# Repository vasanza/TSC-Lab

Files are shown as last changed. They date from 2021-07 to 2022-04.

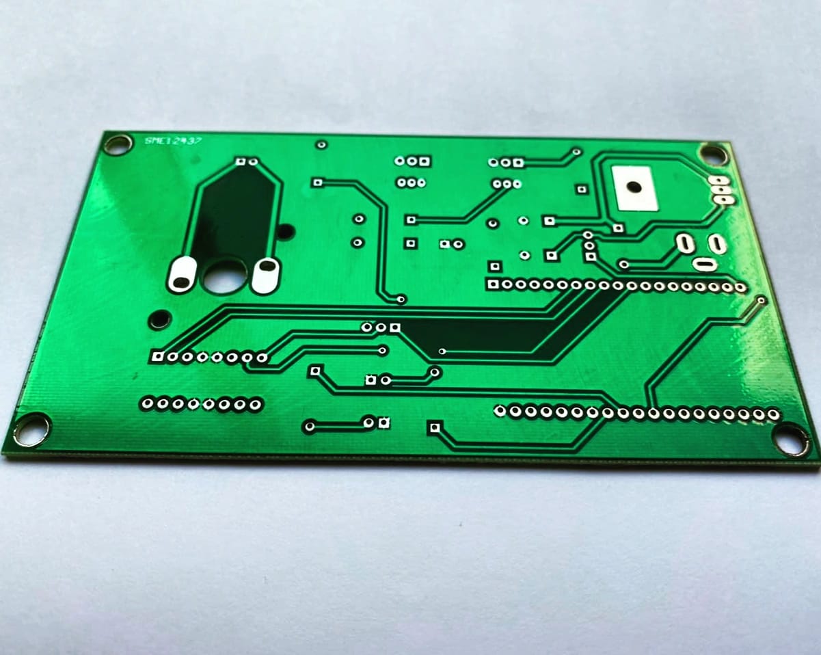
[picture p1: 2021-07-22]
TSC-Lab/PCB2.jpeg

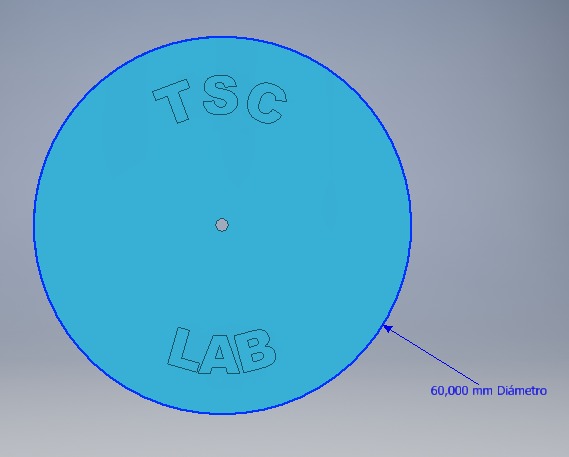
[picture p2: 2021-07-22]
3DPrint/disco.jpeg

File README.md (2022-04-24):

# ⭐⭐⭐⭐⭐ TEMPERATURE AND SPEED CONTROL LAB (TSC-LAB)
- ➡️ #TSCLab #TSC_Lab #TSCLAB #TSC
# Open Source Licenses
oshw_facts

# Open hardware Certification
- https://certification.oshwa.org/ec000003.html
OSHWA TSC-LAB

# About TSC-Lab
TSC-Lab 2
- The Temperature and Speed Control Lab (TSC-Lab) is an application of feedback control with an ESP32, an LED, two heaters, two temperature sensors, one direct current motor and an optical encoder as a revolution per minute (rpm) meter. The heater power output is adjusted to maintain the desired temperature setpoint. Thermal energy from the heater is transferred by conduction, convection, and radiation to the temperature sensor. Heat is also transferred away from the device to the surroundings. On the other hand, the motor speed is adjusted using a motor driver and with PWM signals, allowing the reference speed to be reached using the rpm meter.

# PCB (Top Layer)
PCB1

# PCB (Bottom Layer)
PCB2

# 3D printed parts
TSC-Lab1

# Web page
- http://www.tsc-lab.com/

# Blog
- https://tsc-lab.blogspot.com/

# DataSet
- http://ieee-dataport.org/4138
- http://ieee-dataport.org/4477

# Repository technical specifications
- **IDE:** Arduino 1..8.13
- **DEVICE:** TSC-LAB
- **Hardware Core:** ESP32 - WROOM32

# Keynote
## Clone
- git status
- git clone https://github.com/vasanza/TSC-Lab.git

## Switched to Branch
- git branch -a
- git checkout NameBranch

## New Branch
- git checkout -b NameBranch

## Push
- git pull origin NameBranch
- git status
- git add .
- git status
- git commit -m "message"
- git push origin NameBrach

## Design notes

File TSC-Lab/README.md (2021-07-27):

# Design of printed circuit boards PCBs in Altium Designer 
- https://tsc-lab.blogspot.com/

# PCB (Top Layer)
TSC-Lab 4
PCB1

# PCB (Bottom Layer)
TSC-Lab 5
PCB2

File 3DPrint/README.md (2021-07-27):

# 3D printed parts 
- https://tsc-lab.blogspot.com/

TSC-Lab1
TSC-Lab2

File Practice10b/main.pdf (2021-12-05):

## TEMPERATURE AND SPEED CONTROL LAB (TSC-LAB)

Practice 10: Data acquisition with square velocity input https://tsc-lab.blogspot.com/2021/06/practice-10-data-acquisition-with.html

- Blog: https://tsc-lab.blogspot.com/
- GitHub: https://github.com/vasanza/TSC-Lab
- Matlab functions: https://github.com/vasanza/Matlab_Code
- IEEEDataPort: http://ieee-dataport.org/4138
- TSC-LAB configurations
- int dutyCycleInitial = 255;
- int dutyCycleFinish = 0;
- int period = 13000;
- int cycles = 50;
- 1 sample per second

## Raw dataset preparation

clear;clc;%clear all
addpath(genpath('./src'))%functions folders datapath = fullfile('./data/');%data folder

## Raw dataset preprocessing

filenames = FindCSV(datapath);%List All CSV files data=readtable(fullfile(datapath,filenames(1).name));%Select i CSV file data=table2array(data);
DataNorm = fNormalization(data(:,1));%Normalization
DataFeatures = [max(DataNorm) min(DataNorm) mean(DataNorm)... median(DataNorm) rms(DataNorm) std(DataNorm) ];%Feature extraction

## Plot Raw TSC-LAB dataset

figure
plot(data);xlabel('Samples');ylabel('RPM'); title('Motor Speed');
legend('RPM','PWM');

## Plot Normalization dataset

figure
plot(DataNorm);xlabel('Samples');ylabel('Normalized Values'); title('Normalized data graph');
legend('RPM');

## Select a case

IN=data(:,end);%RPM motor
OUT=data(:,1);%PWM
figure
plot(OUT)
title('OUT');

## System Identification

ident

Warning: The "ident" command is obsolete and may be removed in a future release of MATLAB. Use the "systemIdentification" command instead.

Created preference file C:\Users\vasan\Documents\MATLAB\idprefs.mat.
Type HELP MIDPREFS if you want to move this file.

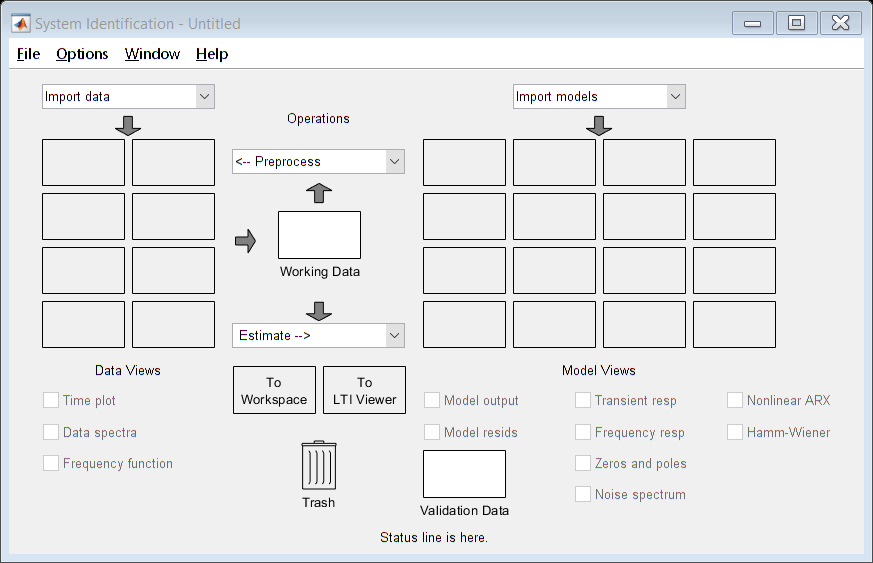
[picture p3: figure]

## Open the Classification Learner

%regressionLearner
%classificationLearner

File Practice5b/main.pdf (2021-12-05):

## TEMPERATURE AND SPEED CONTROL LAB (TSC-LAB)

Práctica 5: Activation of Transistor 1 and 2, also Reading of temperature sensor 1 and 2 https://tsc-lab.blogspot.com/2021/05/practica-5-activation-of-transistor-1.html

- Blog: https://tsc-lab.blogspot.com/
- GitHub: https://github.com/vasanza/TSC-Lab
- Matlab functions: https://github.com/vasanza/Matlab_Code
- IEEEDataPort: http://ieee-dataport.org/4138
- TSC-LAB configurations
- int period = 15; //medium period in minutes
- int freq_sampling = 100; // sampling time
- int ciclos = 20; // sampling time
- 1 sample per second

## Raw dataset preparation

clear;clc;%clear all
addpath(genpath('./src'))%functions folders datapath = fullfile('./data/');%data folder

## Raw dataset preprocessing

filenames = FindCSV(datapath);%List All CSV files data=readtable(fullfile(datapath,filenames(1).name));%Select i CSV file data=table2array(data);
DataNorm = fNormalization(data(:,1:2));%Normalization
DataFeatures = [max(DataNorm) min(DataNorm) mean(DataNorm)... median(DataNorm) rms(DataNorm) std(DataNorm) ];%Feature extraction

## Plot Raw TSC-LAB dataset

figure
plot(data);xlabel('Samples');ylabel('°C'); title('Temperature');
legend('Temp1','Temp2','PWM1','PWM2');

## Plot Normalization dataset

figure
plot(DataNorm);xlabel('Samples');ylabel('Normalized Values'); title('Normalized data graph');
legend('Temp1','Temp2');

## Select a case

num = input('Enter a case: '); switch num
case 1 %Temp1
IN=data(:,end-1);%temp1
OUT=data(:,1);%PWM1
case 2 %Temp2
IN=data(:,end);%temp1
OUT=data(:,2);%PWM1
case 3 %Temp1 and Temp2
IN=[(data(:,end) + data(:,end-1))/2];%temp1 OUT=data(:,1);%PWM1
end
figure
plot(OUT)
title('OUT');

## System Identification

ident

Warning: The "ident" command is obsolete and may be removed in a future release of MATLAB. Use the "systemIdentification" command instead.

Created preference file C:\Users\vasan\Documents\MATLAB\idprefs.mat.
Type HELP MIDPREFS if you want to move this file.


## Open the Classification Learner

%regressionLearner
%classificationLearner

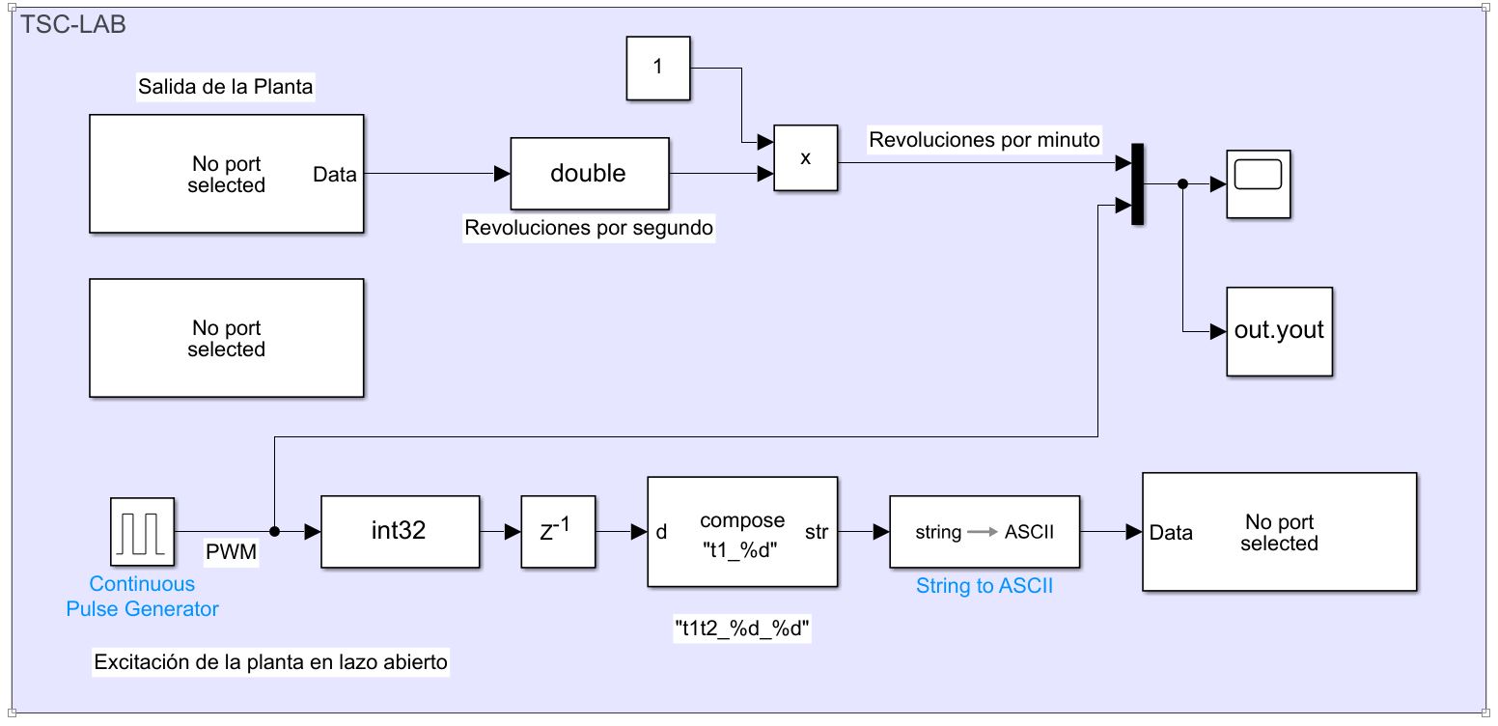
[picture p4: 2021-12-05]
Practice11/Practice11_Str/Practice11_Str.JPG

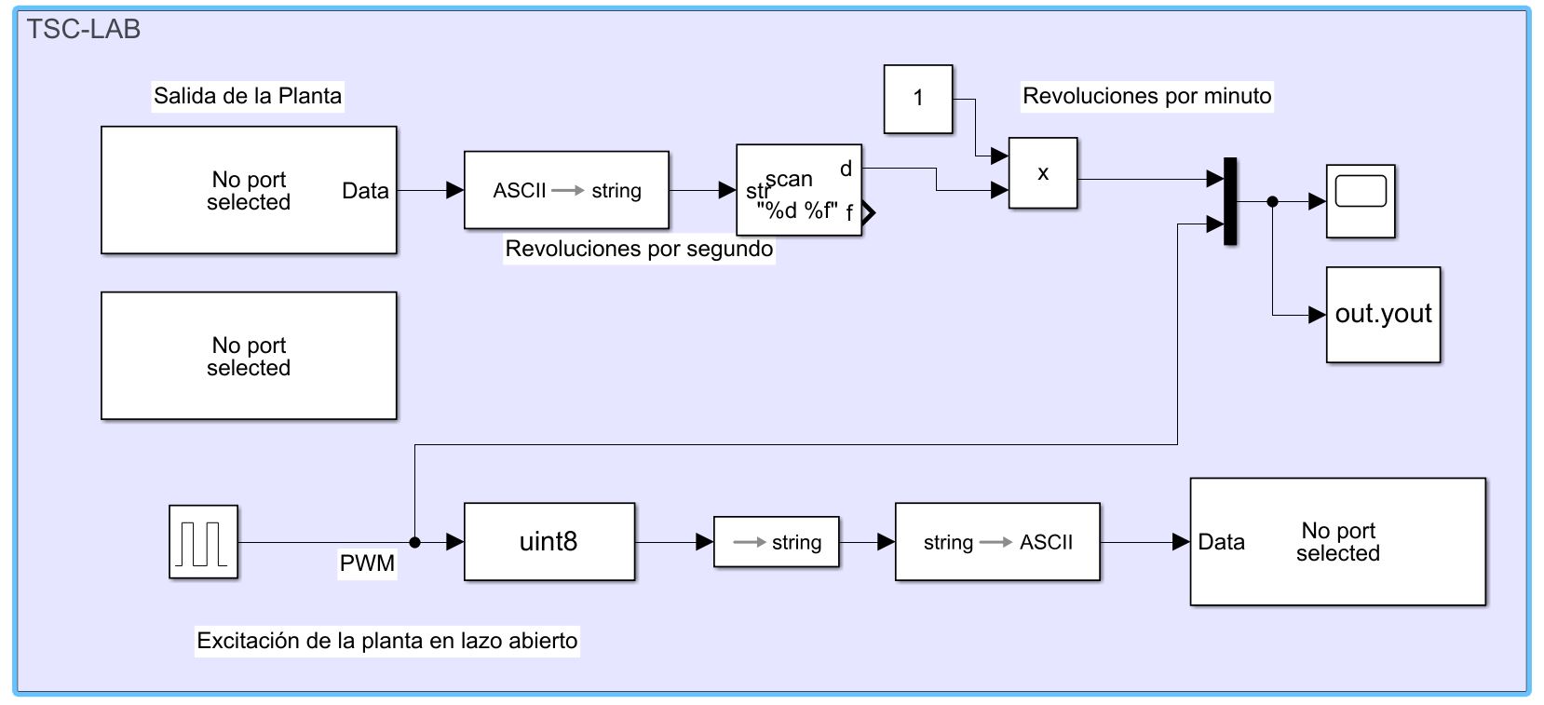
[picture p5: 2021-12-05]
Practice12/Practice12_String/practice12_String.JPG

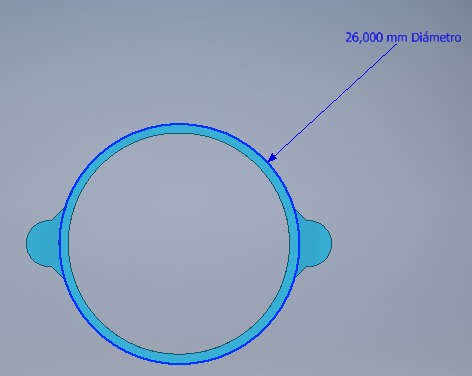
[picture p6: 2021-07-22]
3DPrint/case_motor.jpeg

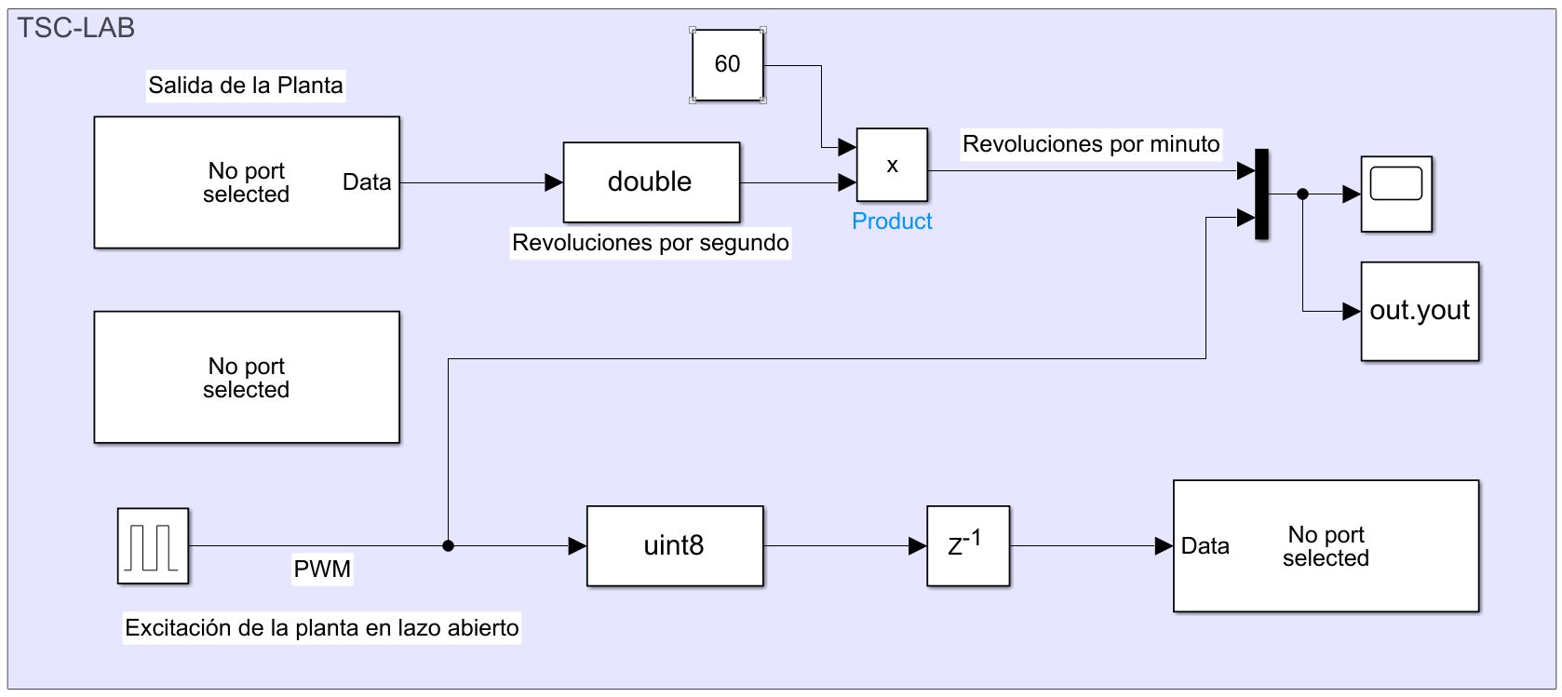
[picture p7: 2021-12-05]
Practice12/Practice12_Byte/Practice12_Byte.JPG

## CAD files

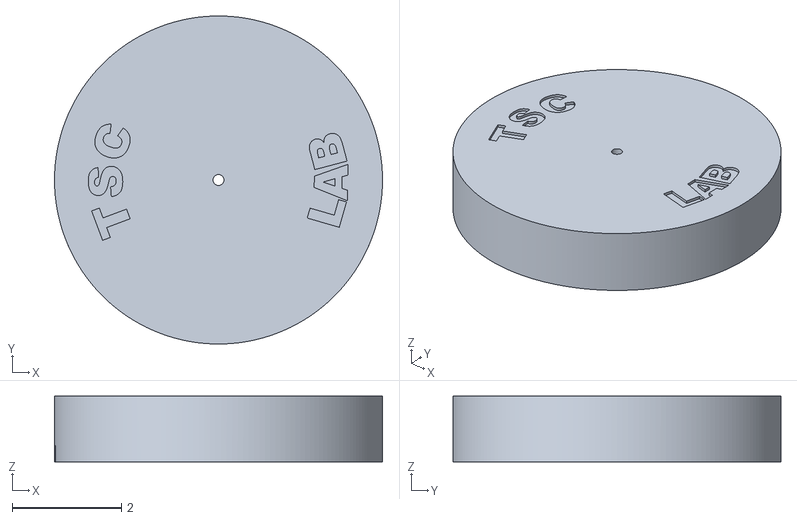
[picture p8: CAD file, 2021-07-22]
3DPrint/disco_lf.stl
6.00 x 6.00 x 1.20

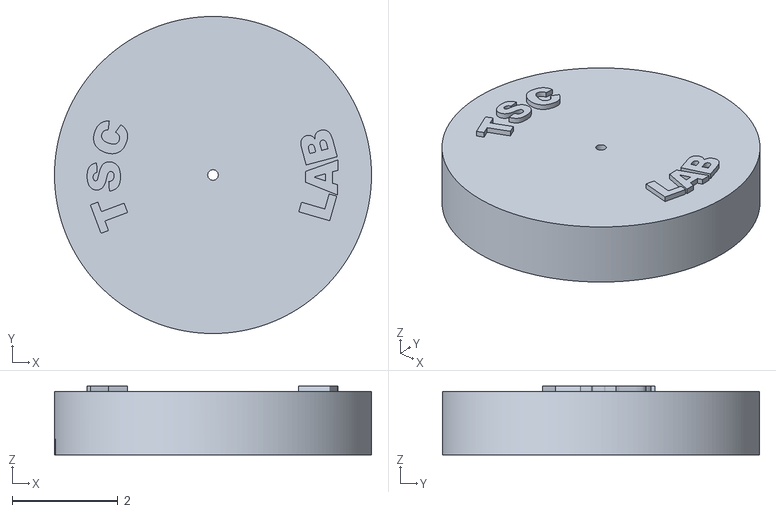
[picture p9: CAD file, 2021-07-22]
3DPrint/disco.stl
6.00 x 6.00 x 1.30

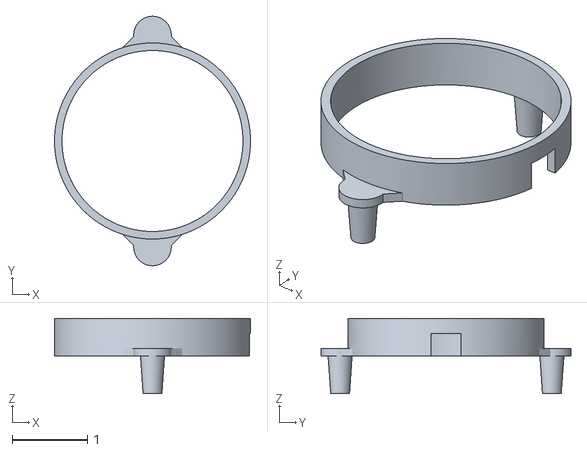
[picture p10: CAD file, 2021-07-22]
3DPrint/case_motor.stl
2.60 x 3.31 x 1.00

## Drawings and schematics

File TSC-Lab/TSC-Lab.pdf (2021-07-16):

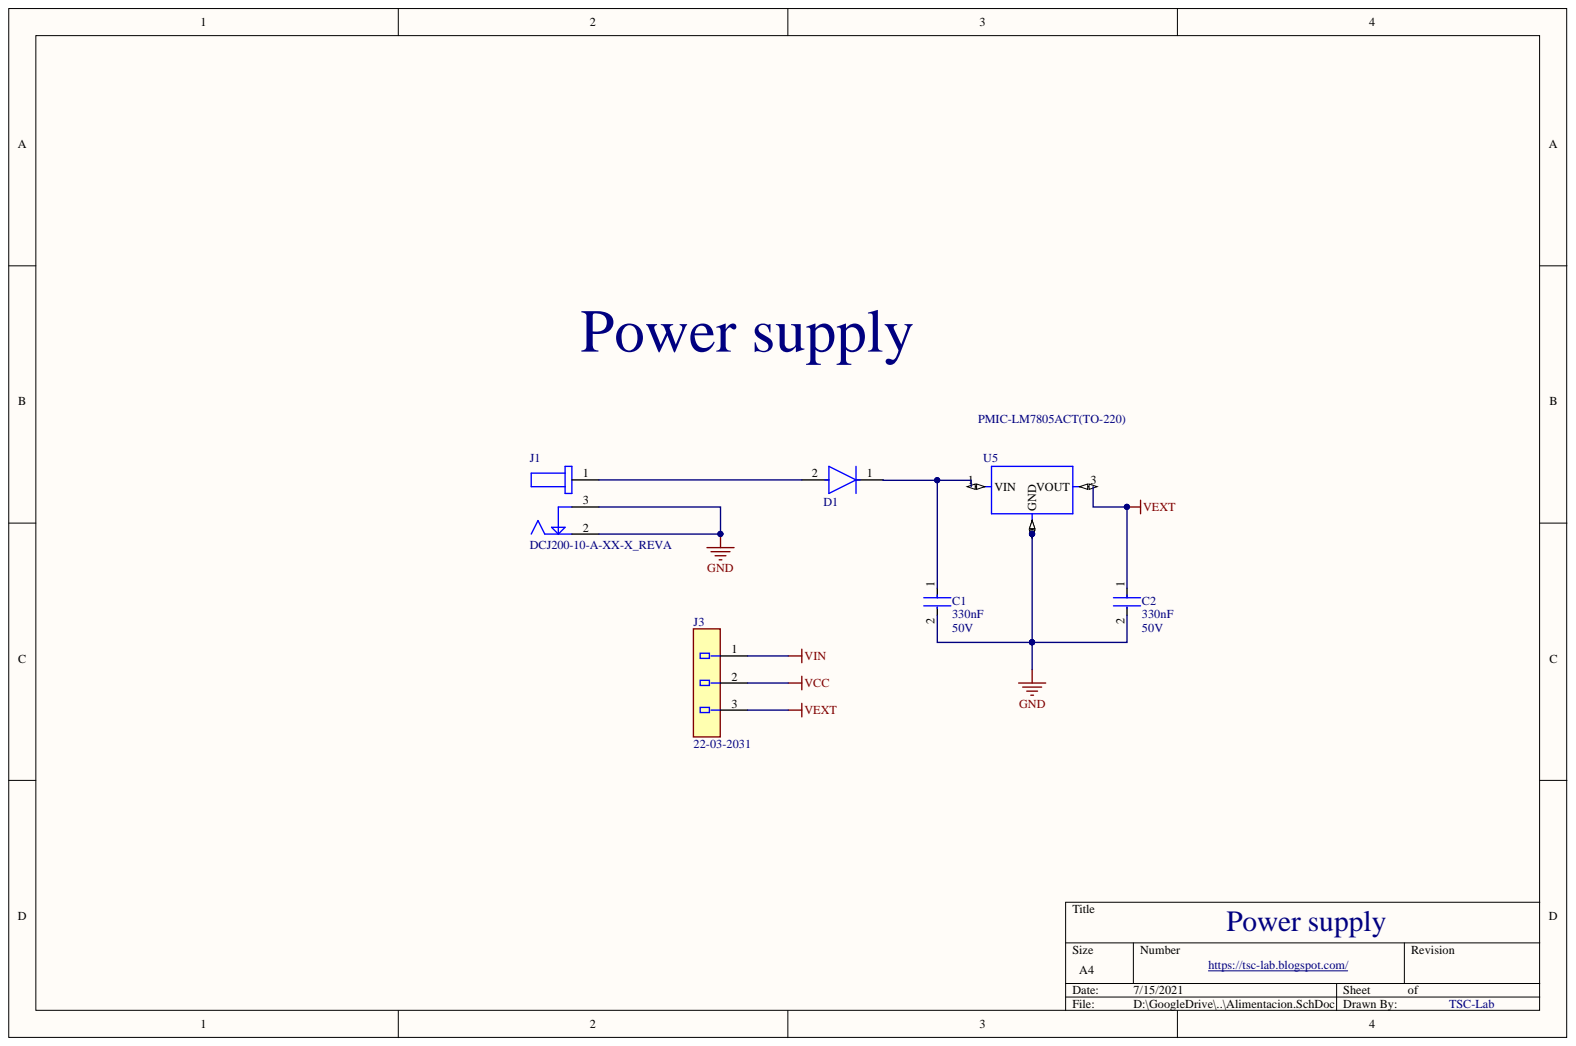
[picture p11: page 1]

Size A4 | Number https://tsc-lab.blogspot.com/ | Revision

Date: 7/15/2021 | Sheet of
File: D:\GoogleDrive\..\Alimentacion.SchDoc | Drawn By: TSC-Lab

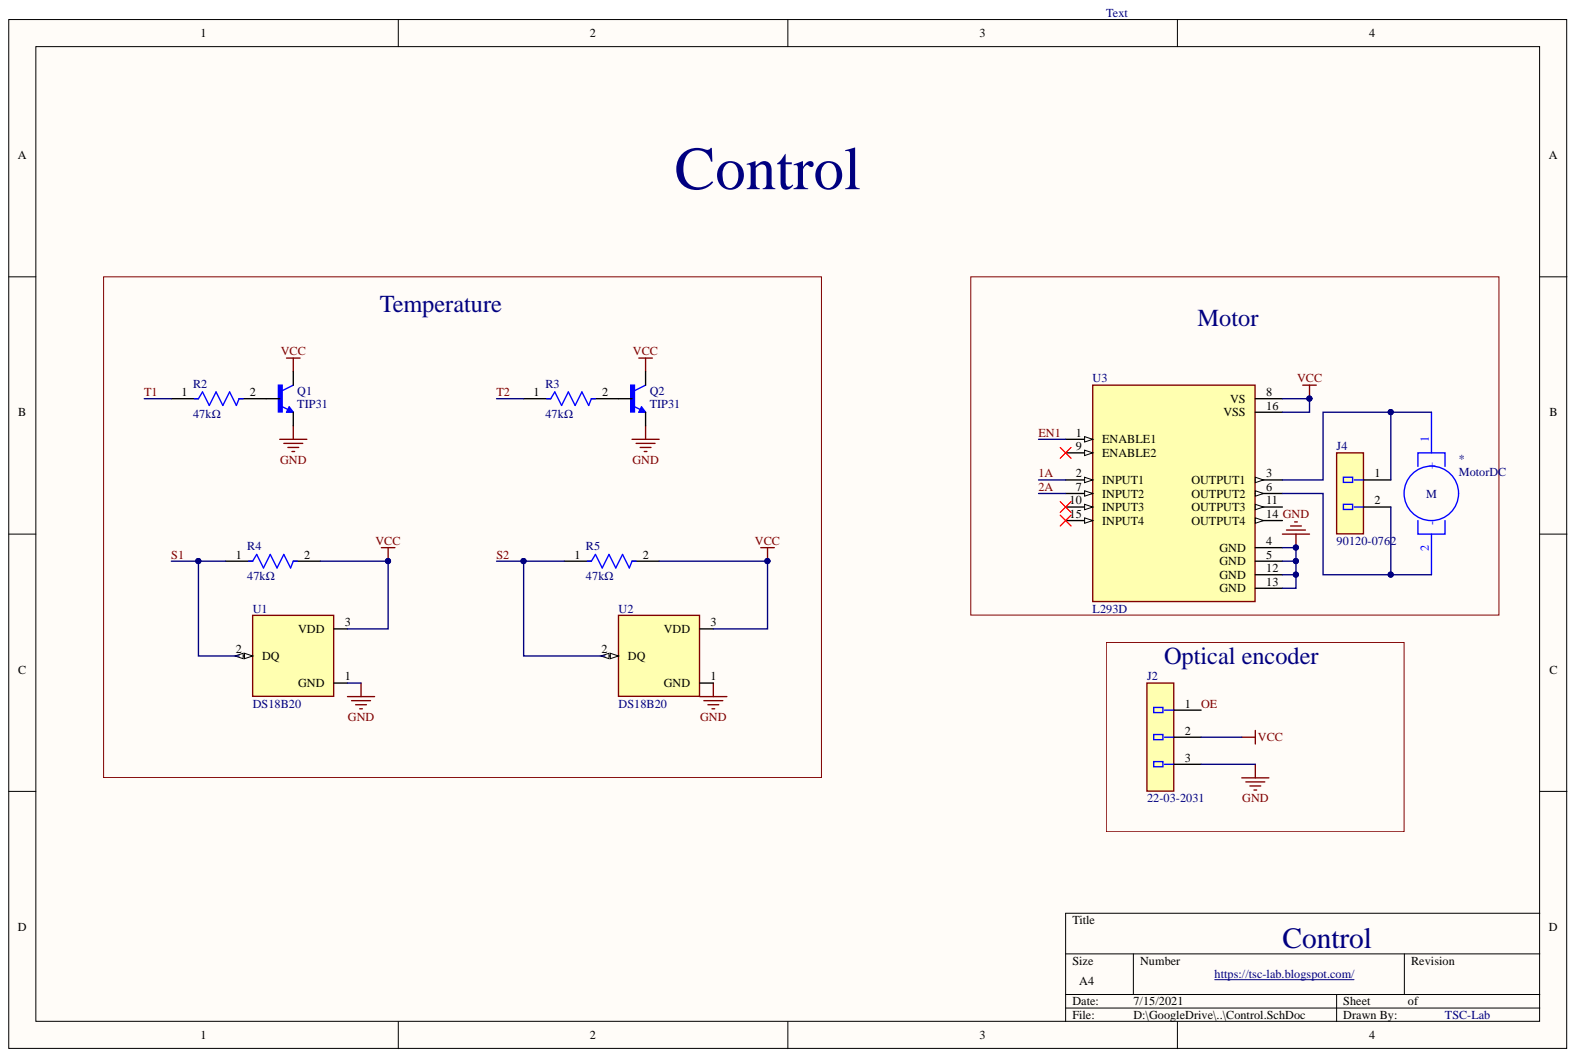
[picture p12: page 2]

1 1 | GND

Size A4 | Number https://tsc-lab.blogspot.com/ | Revision

Date: 7/15/2021 | Sheet of
File: D:\GoogleDrive\..\Control.SchDoc | Drawn By: TSC-Lab

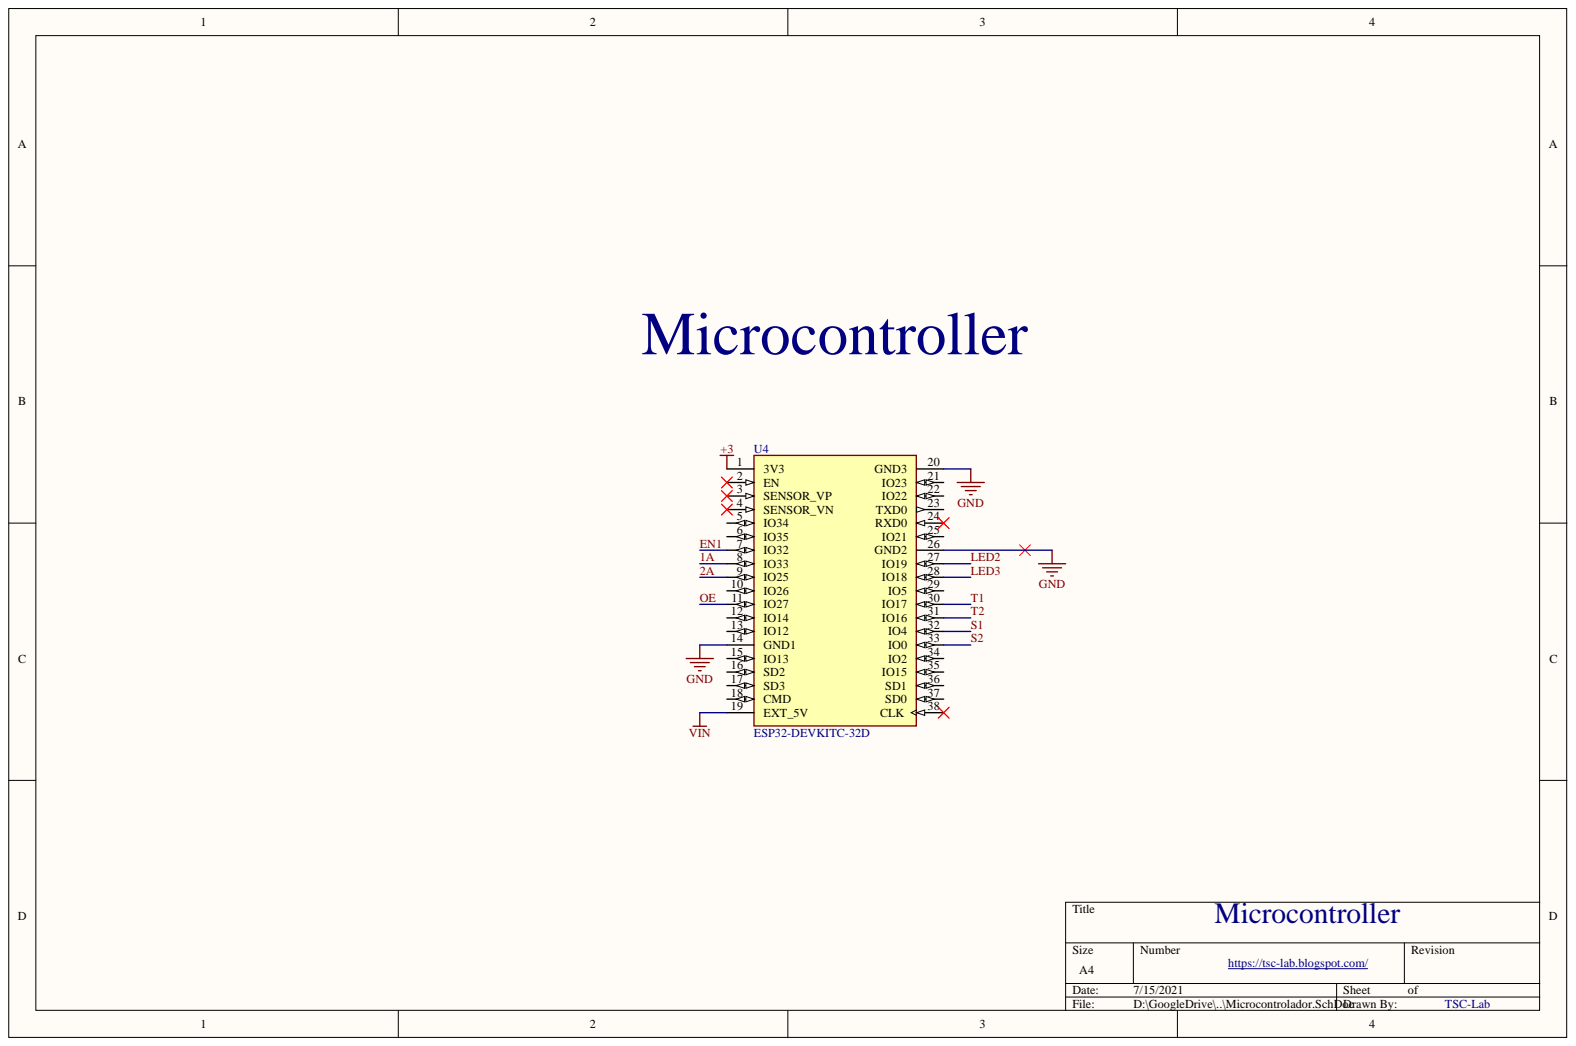
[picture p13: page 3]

Size A4 | Number https://tsc-lab.blogspot.com/ | Revision

Date: 7/15/2021 | Sheet of
File: D:\GoogleDrive\..\Microcontrolador.SchDocDrawn By: | TSC-Lab

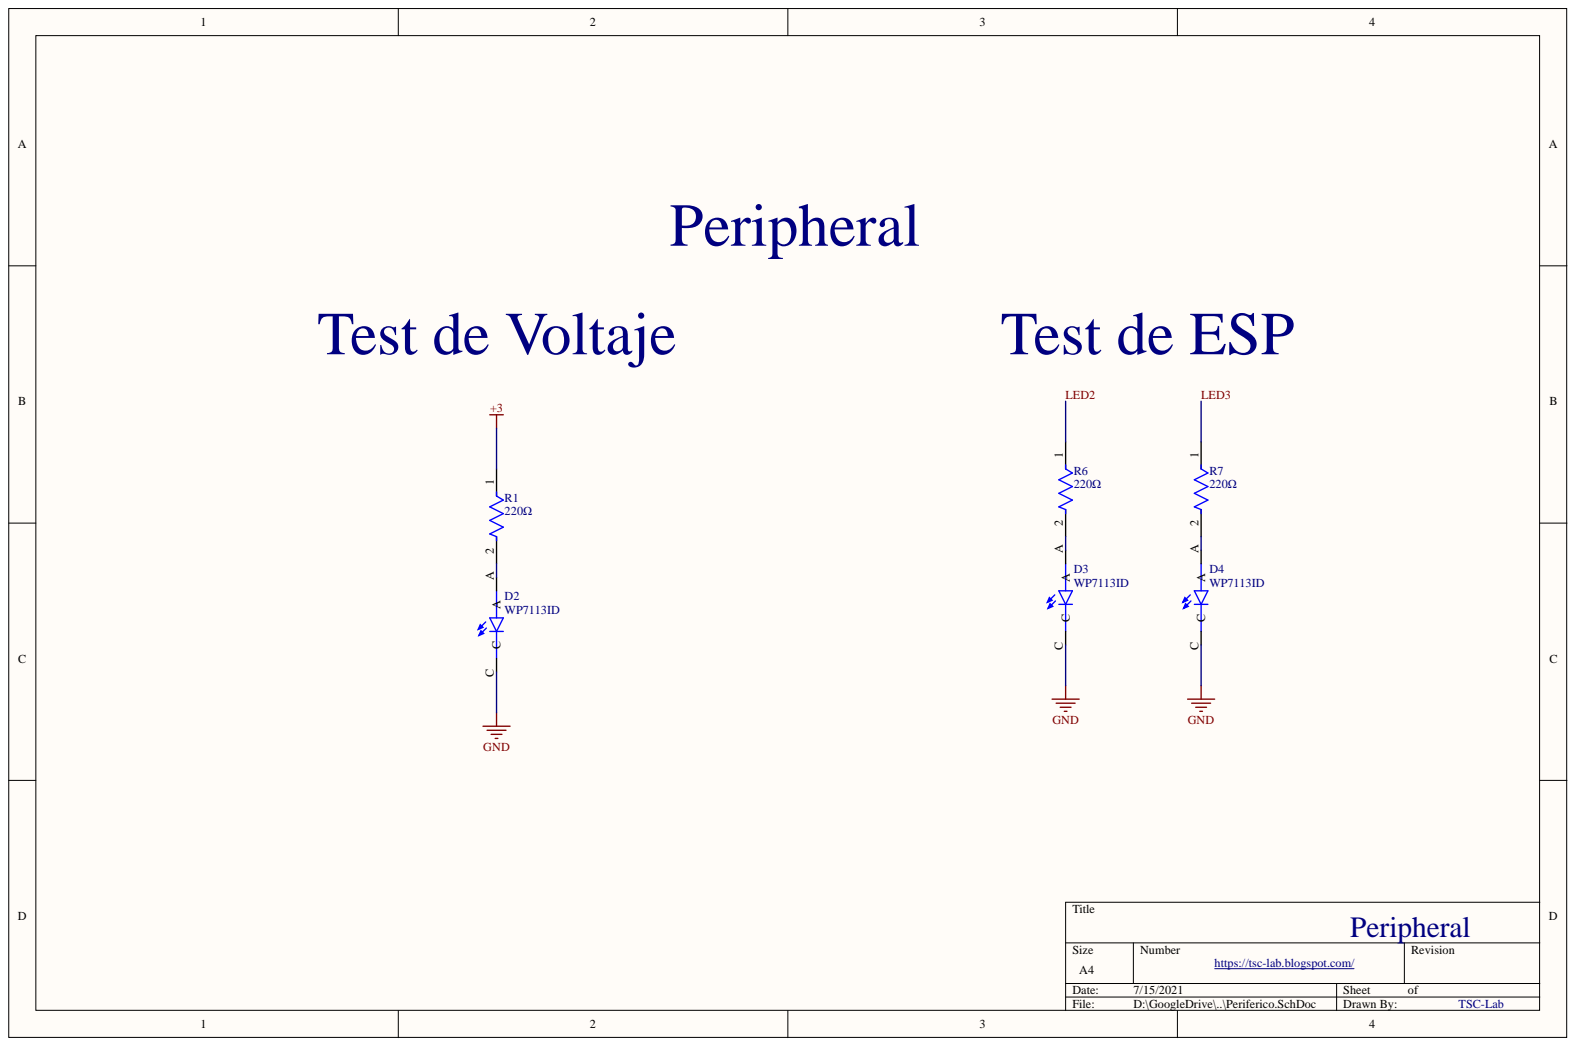
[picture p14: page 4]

Size A4 | Number https://tsc-lab.blogspot.com/ | Revision

Date: 7/15/2021 | Sheet of
File: D:\GoogleDrive\..\Periferico.SchDoc | Drawn By: TSC-Lab

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
D | D
C | C
B | B
A | A

Title

Size A4 | Number https://tsc-lab.blogspot.com/ | Revision
Date: 7/15/2021 | Sheet of
File: D:\GoogleDrive\..\TSC-Lab.SchDoc | Drawn By: TSC-Lab

Designator
Alimentacion.SchDoc

Designator
Microcontrolador.SchDoc

Designator
Control.SchDoc

Designator
Periferico.SchDoc

# TSC-LAb

# 1. Power supply 2. Microcontroller 3. Control 4. Peripheral

# TSC-Lab

The Temperature and Speed Control Lab (TSC-Lab) is an application of feedback control with an ESP32, an LED, two heaters, two temperature sensors, one direct current motor and an optical encoder as a revolution per minute (rpm) meter. The heater power output is adjusted to maintain the desired temperature setpoint. Thermal energy from the heater is transferred by conduction, convection, and radiation to the temperature sensor. Heat is also transferred away from the device to the surroundings. On the other hand, the motor speed is adjusted using a motor driver and with PWM signals, allowing the reference speed to be reached using the rpm meter.

The practice guides that were used in the data acquisition process are detailed in the following blog:
https://tsc-lab.blogspot.com/p/summary.html

The codes used are in the following repository:
https://github.com/vasanza/TSC-Lab

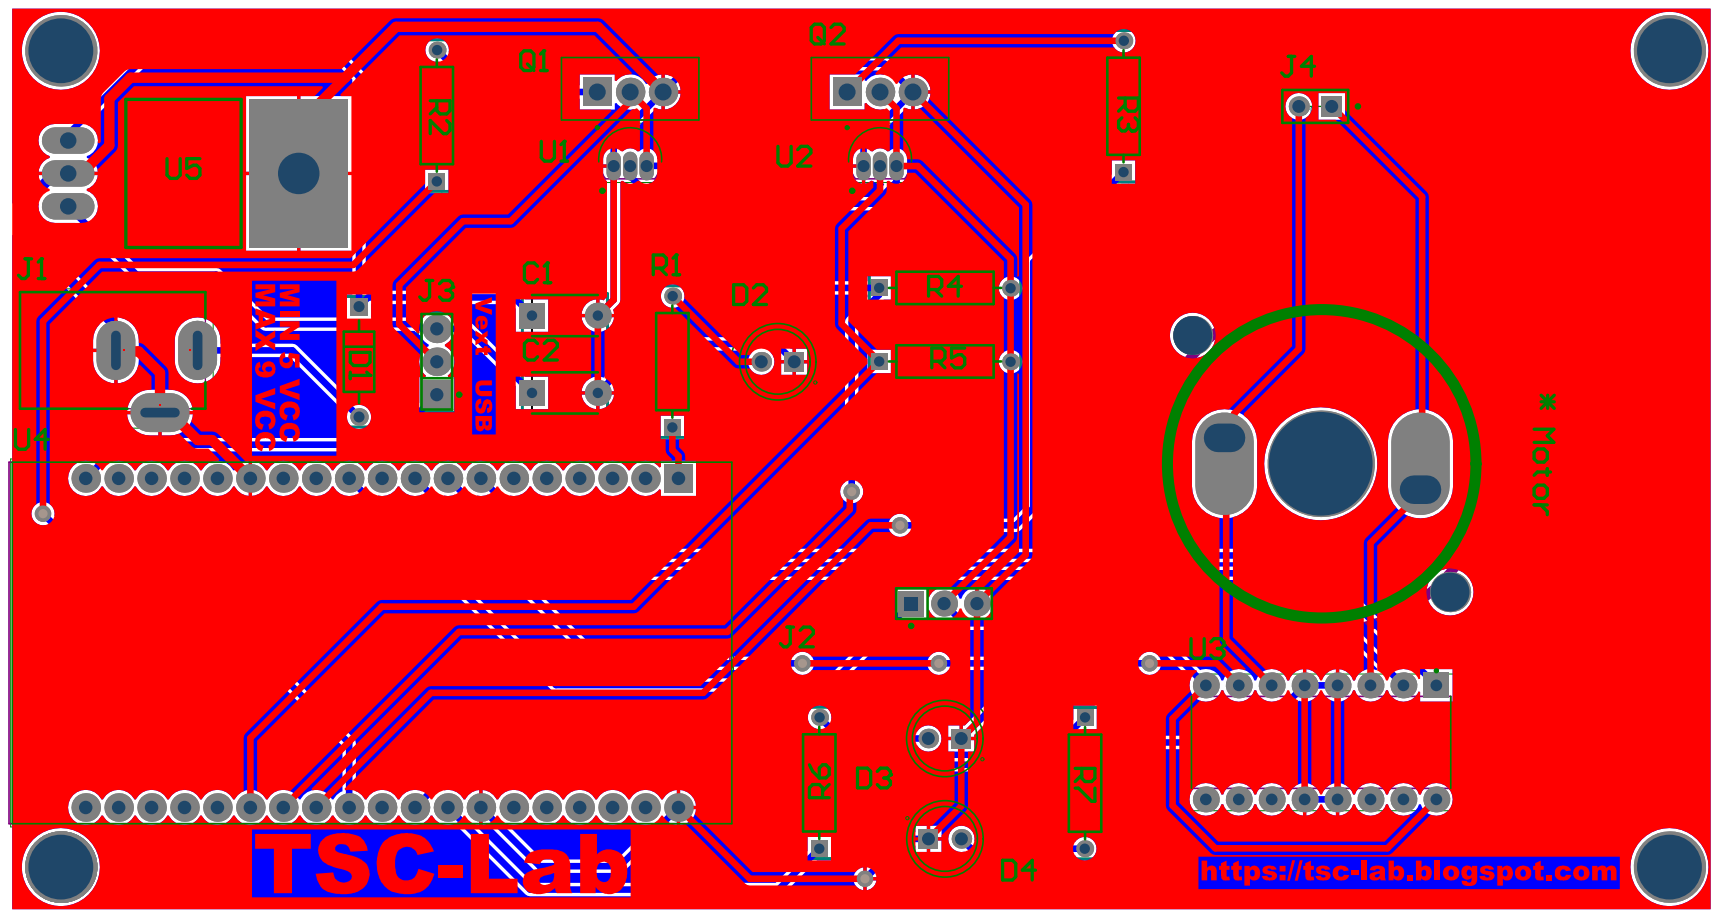
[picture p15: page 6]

Comment | Description | Designator | Footprint | LibRef | Quantity
MotorDC | PCBComponent_1 | MotorDC | 1
Cap_Kemet_C322C334CAPCER0.33UF 50V ZC1 , C2 | Kemet_C322C334M5U5Cap_Kem et_C322C334 | 2
Diode_Vishay_1N4001DIODEGEN PURP 50V D1 | Vishay_1N4001E-E3-5Diode_Vishay_1N4001 | 1
WP7113ID | LED; Thru-Hole; GreenD 2, D3, D 4 | LED_ WP71 13ID | WP7113 ID | 3
DCJ200-10-A-XX-X_REDC Power Jack, Thru-HJ1 | GC T_DCJ200- 10-A-XX- DCJ200-10-A-XX-X_RE | 1
Conn_Molex_22-03-20CON N HEADER 3POS | J2, J3 | Molex_SD-4030-0001_Conn_Molex_22-03-20 | 2
Conn_Molex_90120-07CON N HEADER 2POS | J4 | Molex_90120-0762_0 | Conn_Molex_90120-07 | 1
TIP31 | Bipolar (BJT) TransistoQ1 , Q2 | TO2 54P1060X4 82 X222TIP31 | 2
Res_Vishay_SFR25000RES220 OHM 0.4W 1%R1, R2, R3, R4, R5, R6Vis hay_SFR250000220Res_Vis hay_SFR25000 | 7
DS18B20 | digital thermometer -5U1, U2 | TO-92-TO92127P495HDS18B2 0 | 2
L293D | 4-Channel Motor Driver U3 | DIP880W50P254L2000L293D | 1
ESP32-DEVKITC-32D | Eval Board For Esp-WroU4 | MODULE_ESP32-DEVKIESP32-DEVKITC-32D | 1
PMIC-LM7805ACT(TO-310030049 | U5 | TO-220 | PMIC-LM7805ACT(TO- | 1

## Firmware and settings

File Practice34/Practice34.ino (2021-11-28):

/*
   ****************************** TSC-Lab *******************************
   ***************************** PRACTICE 34 *****************************
   This practice is about use of two core esp-32
   By: Kevin E. Chica O
   More information: https://tsc-lab.blogspot.com/
*/
//temperature
#include <OneWire.h>
#include <DallasTemperature.h>
// GPIO pin 0 is set as OneWire bus
OneWire ourWire1(0);
//GPIO pin 4 is set as OneWire bus
OneWire ourWire2(4);

//A variable or object is declared for our sensor 1
DallasTemperature sensors1(&ourWire1);
//A variable or object is declared for our sensor 2
DallasTemperature sensors2(&ourWire2);

//set parameters
int period_temp = 12; //medium period
int freq_temp = 2000; // sampling time



//motor

//initial setting for data acquisition
int dutyCycleInitial = 255;
int dutyCycleFinish = 0;
int period = 13000;
int cycles = 10;




//separador library
#include <Separador.h>
Separador s;




//motor
int motor1Pin1 = 33;
int motor1Pin2 = 25;
int enable1Pin = 32;

int motor_status = 255;


// Setting PWM properties
const int freq = 30000;
const int pwmChannel = 0;
const int resolution = 8;

//move
String move_motor = "counterclockwise";

int encoder = 27;

void motor( void *pvParameters );

void RPM( void *pvParameters );
void readTemperature( void *pvParameters );

volatile int counter = 0;


void interruption()    // Function that runs during each interrupt
{
  counter++;
}

void setup() {
  Serial.begin(115200);
  //begin temperature sensor
  sensors1.begin();   //Sensor 1 starts
  sensors2.begin();   //Sensor 2 starts


  // sets the pins as outputs:
  pinMode(motor1Pin1, OUTPUT);
  pinMode(motor1Pin2, OUTPUT);
  pinMode(enable1Pin, OUTPUT);

  // configure LED PWM functionalitites
  ledcSetup(pwmChannel, freq, resolution);

  // attach the channel to the GPIO to be controlled
  ledcAttachPin(enable1Pin, pwmChannel);



  attachInterrupt(encoder, interruption, RISING);


  xTaskCreatePinnedToCore(
    motor
    ,  "MotorDC"         // Descriptive name of the function (MAX 8 characters)
    ,  2048              // Size required in STACK memory
    ,  NULL              // INITIAL parameter to receive (void *)
    ,  1                 // Priority, priority = 3 (configMAX_PRIORITIES - 1) is the highest, priority = 0 is the lowest.
    ,  NULL              // Variable that points to the task (optional)
    , 1);                // core 1


  xTaskCreatePinnedToCore(
    RPM
    ,  "RPM"              // Descriptive name of the function (MAX 8 characters)
    ,  2048              // Size required in STACK memory
    ,  NULL              // INITIAL parameter to receive (void *)
    ,  1                 // Priority, priority = 3 (configMAX_PRIORITIES - 1) is the highest, priority = 0 is the lowest.
    ,  NULL              // Variable that points to the task (optional)
    , 1);                // core 1

    xTaskCreatePinnedToCore(
    readTemperature
    ,  "rTemp"              // Descriptive name of the function (MAX 8 characters)
    ,  2048              // Size required in STACK memory
    ,  NULL              // INITIAL parameter to receive (void *)
    ,  1                 // Priority, priority = 3 (configMAX_PRIORITIES - 1) is the highest, priority = 0 is the lowest.
    ,  NULL              // Variable that points to the task (optional)
    , 0);                // core 0



}

void loop() {
}

void motor( void *pvParameters ) {
  while (1) {
    if (cycles > 0) {
      digitalWrite(motor1Pin1, HIGH);
      digitalWrite(motor1Pin2, LOW);
      ledcWrite(pwmChannel, dutyCycleInitial);

      motor_status = 255;
      vTaskDelay(period);


      digitalWrite(motor1Pin1, HIGH);
      digitalWrite(motor1Pin2, LOW);
      ledcWrite(pwmChannel, dutyCycleFinish);

      motor_status = 0;
      vTaskDelay(period);
      cycles--;
    }
  }
}

void RPM( void *pvParameters ) {
  while (1) {

    vTaskDelay(999);
    Serial.print(counter * 60);
    Serial.print(",");
    Serial.println(motor_status);
    counter = 0;

  }
}



void readTemperature( void *pvParameters ) {
  while (1) {

    uint32_t timer = period_temp * 60000L;

    for ( uint32_t tStart = millis();  (millis() - tStart) < timer;  ) {
      //The command is sent to read the temperature
      sensors1.requestTemperatures();
      //Obtain the temperature in ºC of sensor 1
      float temp1 = sensors1.getTempCByIndex(0);

      //The command is sent to read the temperature
      sensors2.requestTemperatures();
      //Obtain the temperature in ºC of sensor 2
      float temp2 = sensors2.getTempCByIndex(0);

      //print to display the temperature change
      Serial.println();
      Serial.print(temp1);
      Serial.print(",");
      Serial.println(temp2);          
      delay(freq_temp);
    }

  }
}

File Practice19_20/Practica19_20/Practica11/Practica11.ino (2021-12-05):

/*
   ****************************** TSC-Lab *******************************
   ***************************** PRACTICE 11 *****************************
   This practice is about data acquisition with square velocity input
   By: Kevin E. Chica O
   Reviewed: vasanza
   More information: https://tsc-lab.blogspot.com/
*/
//separador library
#include <Separador.h>
Separador s;

//initial setting for data acquisition
#include <OneWire.h>
#include <DallasTemperature.h>

//GPIO pin 4 is set as OneWire bus
OneWire ourWire1(4);
//GPIO pin 0 is set as OneWire bus
OneWire ourWire2(0);

//A variable or object is declared for our sensor 1
DallasTemperature sensors1(&ourWire1);
//A variable or object is declared for our sensor 2
DallasTemperature sensors2(&ourWire2);

//Status of transistors
int t1 = 0;
int t2 = 0;
//pins of transistor
int trans1 = 17;
int trans2 = 16;

//set parameters

int dutyCycle1 = 0;
int dutyCycle2 = 0;
int band = 0;

// Setting PWM properties
const int freq = 30000;
const int pwmChannell = 0;
const int pwmChannel2 = 1;
const int resolution = 8;



void transistor( void *pvParameters );
void temperature( void *pvParameters );
void pwm( void *pvParameters );



void setup() {
  Serial.begin(115200);
  // sets the pins as outputs:
  sensors1.begin();   //Sensor 1 starts
  sensors2.begin();   //Sensor 2 starts

  //transistor 1
  pinMode(trans1, OUTPUT);
  //transitor 2
  pinMode(trans2, OUTPUT);;

  // configure LED PWM functionalitites
  ledcSetup(pwmChannell, freq, resolution);
  ledcSetup(pwmChannel2, freq, resolution);
  // attach the channel to the GPIO to be controlled
  ledcAttachPin(trans1, pwmChannell);
  ledcAttachPin(trans2, pwmChannel2);

  xTaskCreatePinnedToCore(
    transistor
    ,  "trans"         // Descriptive name of the function (MAX 8 characters)
    ,  2048              // Size required in STACK memory
    ,  NULL              // INITIAL parameter to receive (void *)
    ,  1                 // Priority, priority = 3 (configMAX_PRIORITIES - 1) is the highest, priority = 0 is the lowest.
    ,  NULL              // Variable that points to the task (optional)
    , 1);                // core 1

  xTaskCreatePinnedToCore(
    temperature
    ,  "temp"              // Descriptive name of the function (MAX 8 characters)
    ,  2048              // Size required in STACK memory
    ,  NULL              // INITIAL parameter to receive (void *)
    ,  1                 // Priority, priority = 3 (configMAX_PRIORITIES - 1) is the highest, priority = 0 is the lowest.
    ,  NULL              // Variable that points to the task (optional)
    , 1);                // core 0

  xTaskCreatePinnedToCore(
    pwm
    ,  "PWM"              // Descriptive name of the function (MAX 8 characters)
    ,  2048              // Size required in STACK memory
    ,  NULL              // INITIAL parameter to receive (void *)
    ,  1                 // Priority, priority = 3 (configMAX_PRIORITIES - 1) is the highest, priority = 0 is the lowest.
    ,  NULL              // Variable that points to the task (optional)
    , 1);                // core 0
}

void loop() {
}

void transistor( void *pvParameters ) {
  while (1) {

    ledcWrite(pwmChannell, dutyCycle1);
    ledcWrite(pwmChannel2, dutyCycle2);
    //vTaskDelay(period);
  }
}

// Calcula las RPM quye tiene el motor
void temperature( void *pvParameters ) {
  while (1) {
    vTaskDelay(999);
    //Serial.println(counter * 60);//255 -> 0x32 0x35 0x35
    sensors1.requestTemperatures();
    //Obtain the temperature in ºC of sensor 1
    int temp1 = sensors1.getTempCByIndex(0);

    //The command is sent to read the temperature
    sensors2.requestTemperatures();
    //Obtain the temperature in ºC of sensor 2
    int temp2 = sensors2.getTempCByIndex(0);
    //Serial.write((byte*)&temp1,4);//value temeprature 1
    //Serial.print("la banda es: ");//value temperature 1
    //Serial.println(temp1);//value temperature 1
    if (band == 0) {
      //Serial.println("t1");
      Serial.write(temp1);//value temperature 1
      
    } else if (band == 1) {
      //Serial.println("t2");
      Serial.write(temp2);//value temperature 2
    } else if (band == 2) {
      int tempProm = (temp1 + temp2) / 2;
      //Serial.println("t1t2");
      Serial.write(tempProm);//value temperature 2
      tempProm = 0;


    }
  }
}

// Read del PWM que viene desde Matlab
void pwm( void *pvParameters ) {
  while (1) {
    //Serial.println("hola");
    if (Serial.available())
    {
      /*Cases:
         t1_pwm
         t2_pwm
         t1t2_pwm1_pwm2
      */
      String string = Serial.readStringUntil('\n');
      String nameTrans = s.separa(string, '_', 0);
      int dutyCycle = s.separa(string, '_', 1).toInt();
      //dutyCycle = string.toInt();
      if (nameTrans == "t1") {
        band = 0;
        dutyCycle1 = dutyCycle;
        dutyCycle2 = 0;
      } else if (nameTrans == "t2") {
        band = 1;
        dutyCycle2 = dutyCycle;
        dutyCycle1 = 0;
      } else if (nameTrans == "t1t2") {
        band = 2;
        dutyCycle1 = dutyCycle;
        dutyCycle2 = s.separa(string, '_', 2).toInt();
      }


    }
  }
}

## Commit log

2021-04-25 Folder of practice 2 with arduino code
2021-04-25 add case_1.csv
    [case_1.csv]
2021-04-25 Arduino code of practice 2
2021-04-25 add case 2 and change arduino code
    [case_2.csv]
2021-04-25 Practica 2
    [case_1.csv, case_2.csv]
2021-05-02 all data and code upload
    [case_2.csv, case_3.csv, case_4.csv]
2021-05-02 all dataset and code upload
    [case_3.csv, case_4.csv, texto_prueba_csv.csv]
2021-06-06 edit practice 9 and 10, also dataset of practice 10
    [practice10_data.csv]
2021-07-11 practice 9 and 10 upload one more time
    [practice10.csv, practice10_data.csv]
2021-07-13 Altium Designer TSC-Lab
    % Read more:
    https://tsc-lab.blogspot.com/
    [TSC-Lab.PrjPcb]
2021-07-13 Update Readme
    % Read more: https://tsc-lab.blogspot.com/
    %Dataset: https://ieee-dataport.org/documents/temperature-and-speed-control-lab-tsc-lab
2021-07-13 Add files via upload
    // TSC-LAB
    // Blog: https://tsc-lab.blogspot.com
    // More examples: https://github.com/vasanza/TSC-Lab
    // Dataset: http://ieee-dataport.org/4138
    [Alimentacion.SchDoc, Control.SchDoc, Microcontrolador.SchDoc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]
2021-07-13 dataset of practice 10 (motor plant)
    [practice10.csv]
2021-07-16 TSC-LAB Schematics and PCB Files
2021-07-16 TSC-Lab Documentation (PCB and Schematics)
2021-07-22 3D Print
    Motor case and disc
    [case_motor.stl, disco.stl]
2021-07-22 update disc
    [disco.stl]
2021-07-22 3d print update
    motor case and disc
    [case_motor.stl, disco.stl]
2021-07-22 figure 3d print
    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
2021-07-22 Update PCB layer
2021-07-22 Update Disc (low relief)
    [disco_lf.stl]
2021-07-27 3D printed parts
2021-07-27 Design of printed circuit boards PCBs
2021-12-05 pwm configuration
